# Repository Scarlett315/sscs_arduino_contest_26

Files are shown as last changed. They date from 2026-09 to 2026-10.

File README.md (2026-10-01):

Documentation & process can be found [here](https://medium.com/@scarlettchen315/lock-in-box-2-functional-version-dc13c8e9974b).

Includes 3-D printed box, custom PCB, and Arduino code. 
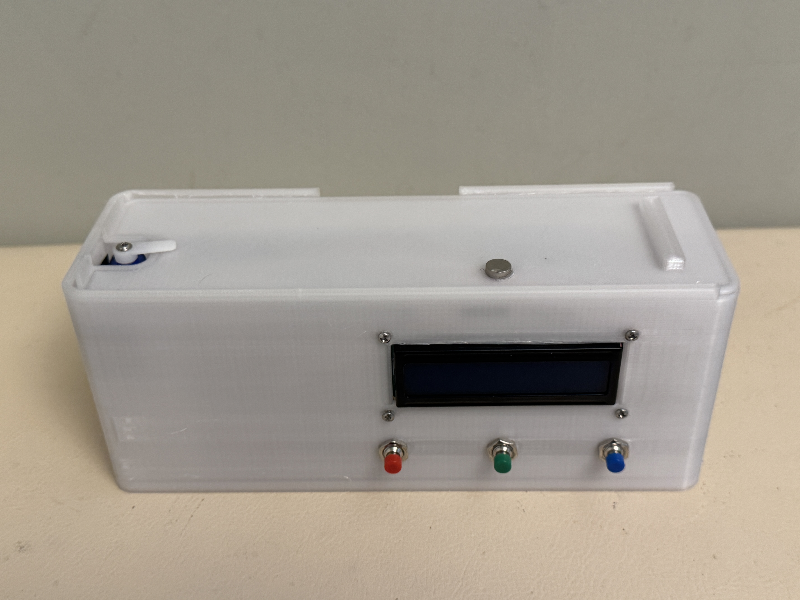
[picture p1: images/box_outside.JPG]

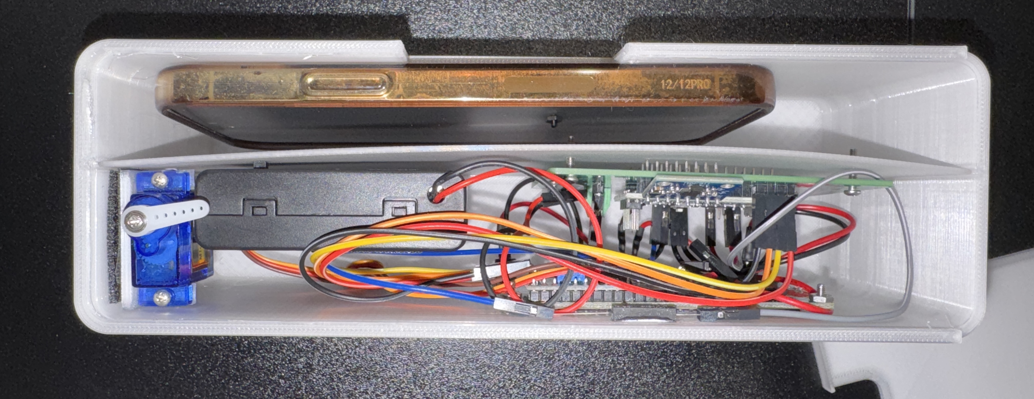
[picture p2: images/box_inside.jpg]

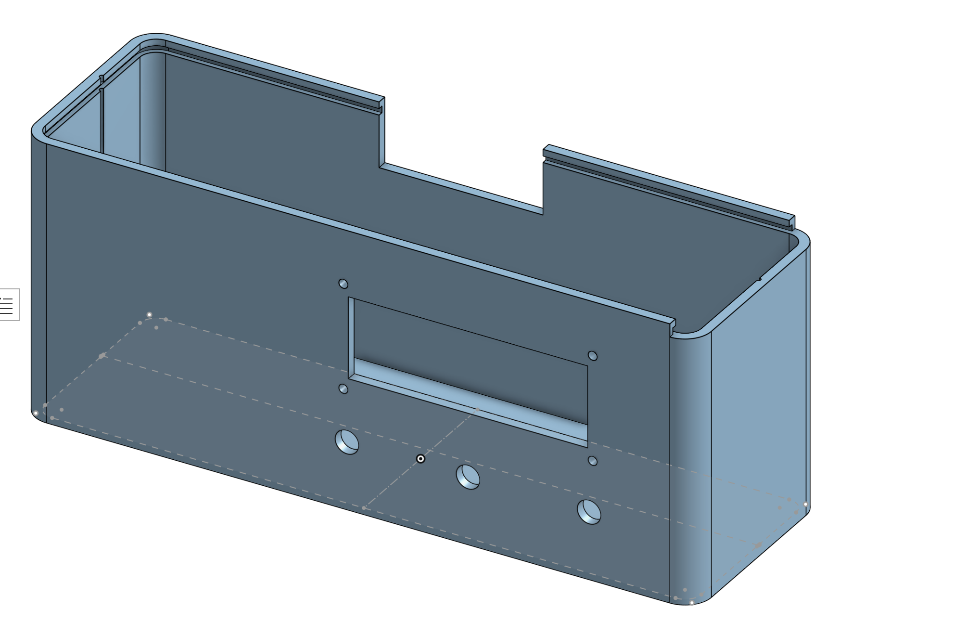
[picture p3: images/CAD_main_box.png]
main box

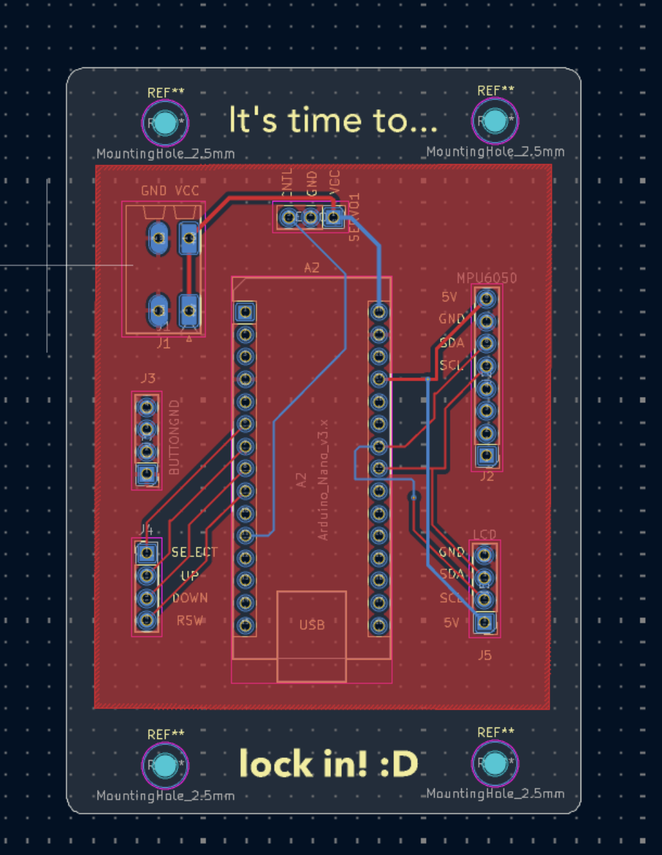
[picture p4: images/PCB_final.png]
PCB


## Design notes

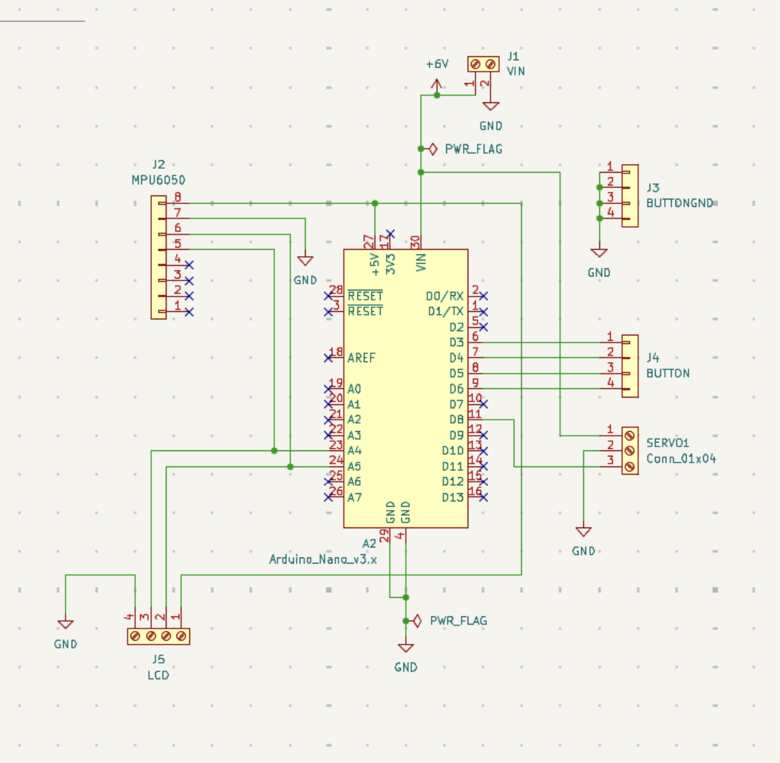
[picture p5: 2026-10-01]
images/schematic_final.png

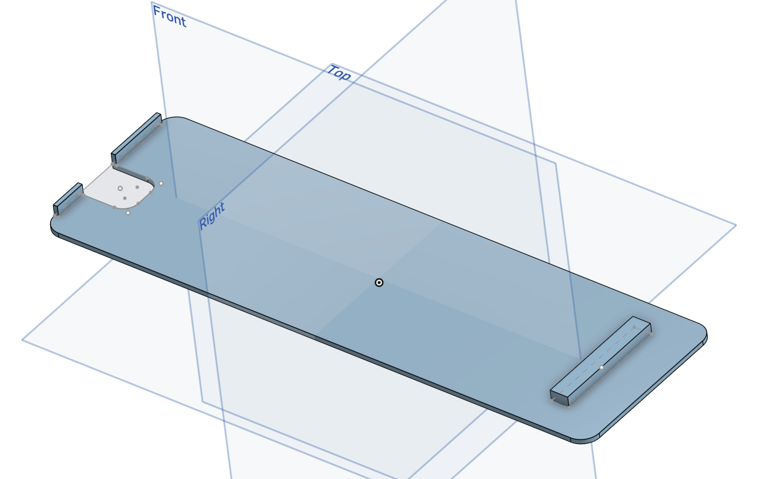
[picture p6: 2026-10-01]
images/CAD_lid.png

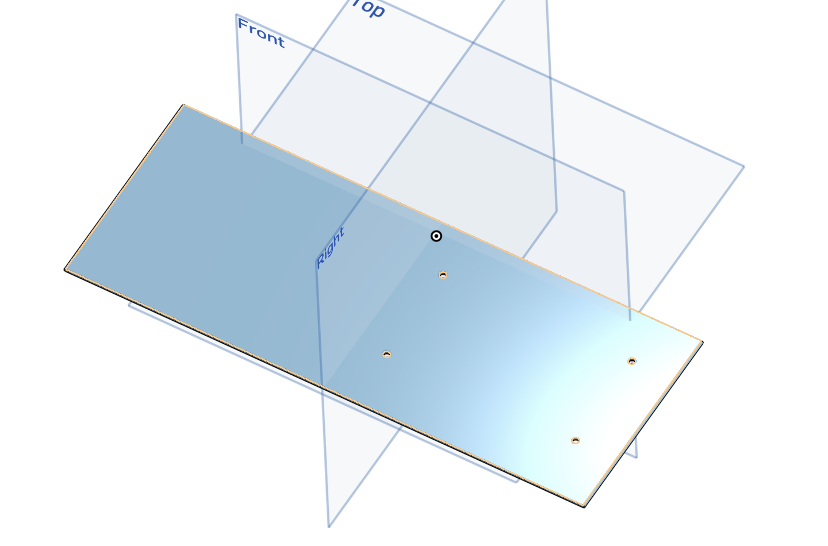
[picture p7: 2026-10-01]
images/CAD_divider.png

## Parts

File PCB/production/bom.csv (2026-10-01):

Designator | Footprint | Quantity | Value | LCSC Part #
A2 | Arduino_Nano | 1 | Arduino_Nano_v3.x
J1 | PhoenixContact_SPT_1.5_2-H-3.5_1x02_P3.5mm_Horizontal | 1 | VIN
J2 | PinHeader_1x08_P2.54mm_Vertical | 1 | MPU6050
J3 | PinHeader_1x04_P2.54mm_Vertical | 1 | BUTTONGND
J4 | PinHeader_1x04_P2.54mm_Vertical | 1 | BUTTON
J5 | PinHeader_1x04_P2.54mm_Vertical | 1 | LCD
SERVO1 | PinHeader_1x03_P2.54mm_Vertical | 1 | Conn_01x04

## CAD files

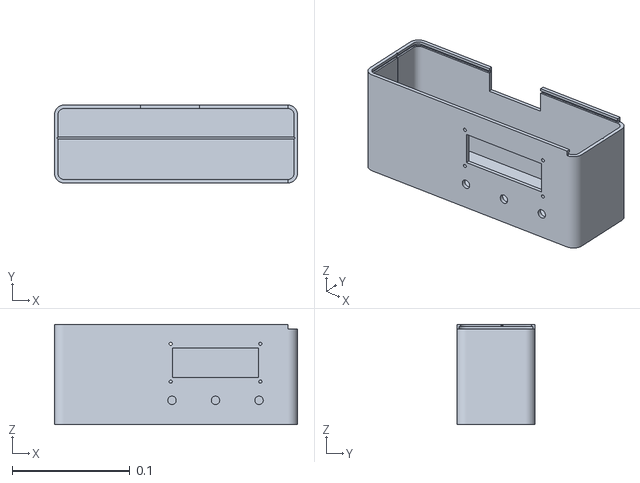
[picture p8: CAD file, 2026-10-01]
CAD Models/main_box_1.stl
0.206 x 0.066 x 0.085

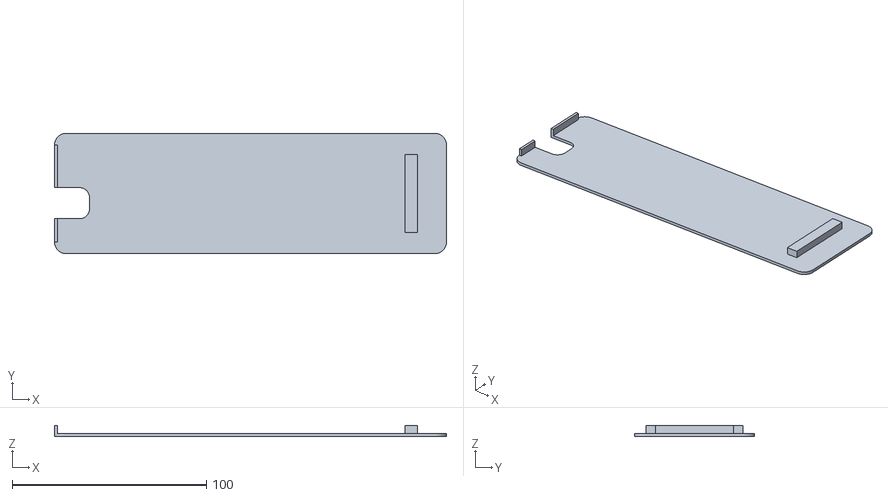
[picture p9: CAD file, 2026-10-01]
CAD Models/lid_2.stl
202.0 x 62.0 x 5.60

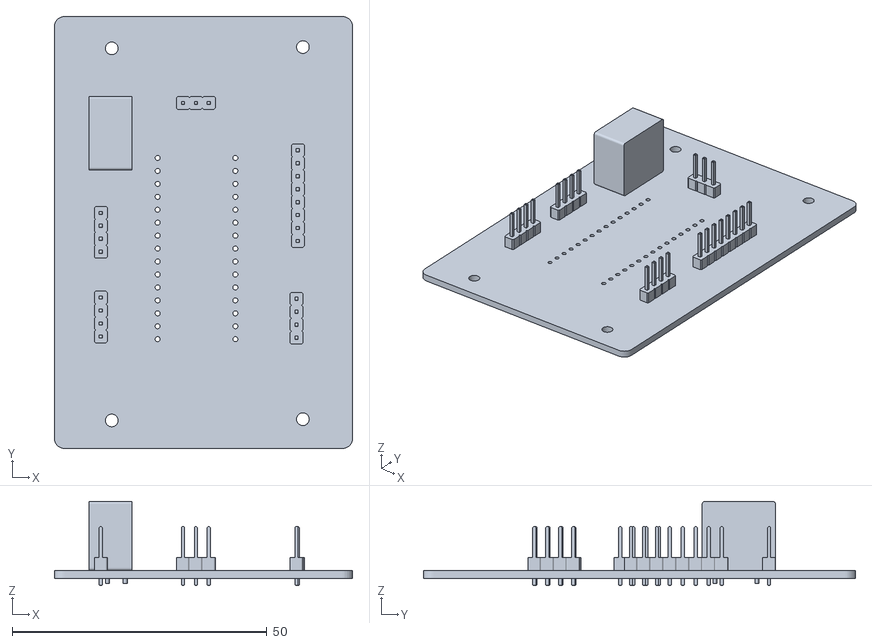
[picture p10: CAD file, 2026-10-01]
PCB/.stl
58.5 x 84.8 x 16.5

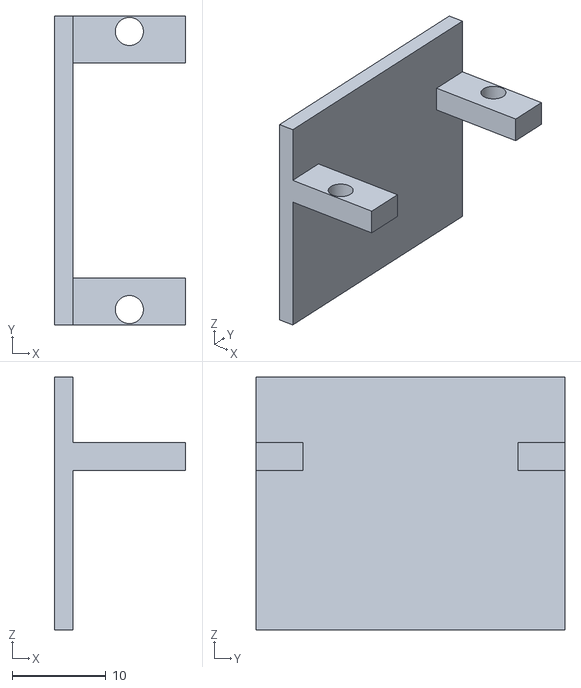
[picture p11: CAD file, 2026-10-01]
CAD Models/servo_holder.stl
14.0 x 33.0 x 27.0

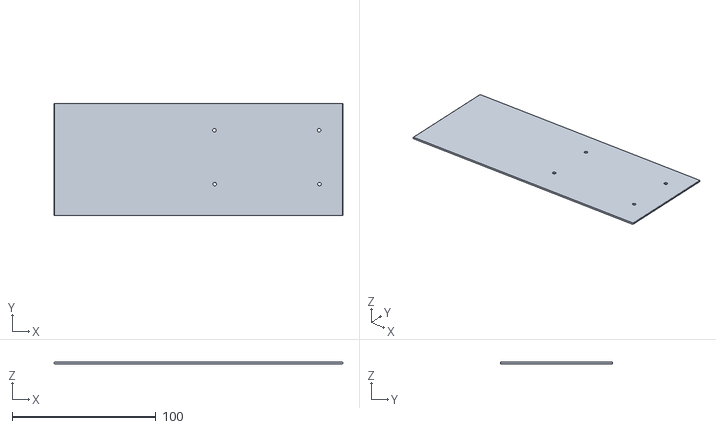
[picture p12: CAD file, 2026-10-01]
CAD Models/divider.stl
201.2 x 78.0 x 1.24

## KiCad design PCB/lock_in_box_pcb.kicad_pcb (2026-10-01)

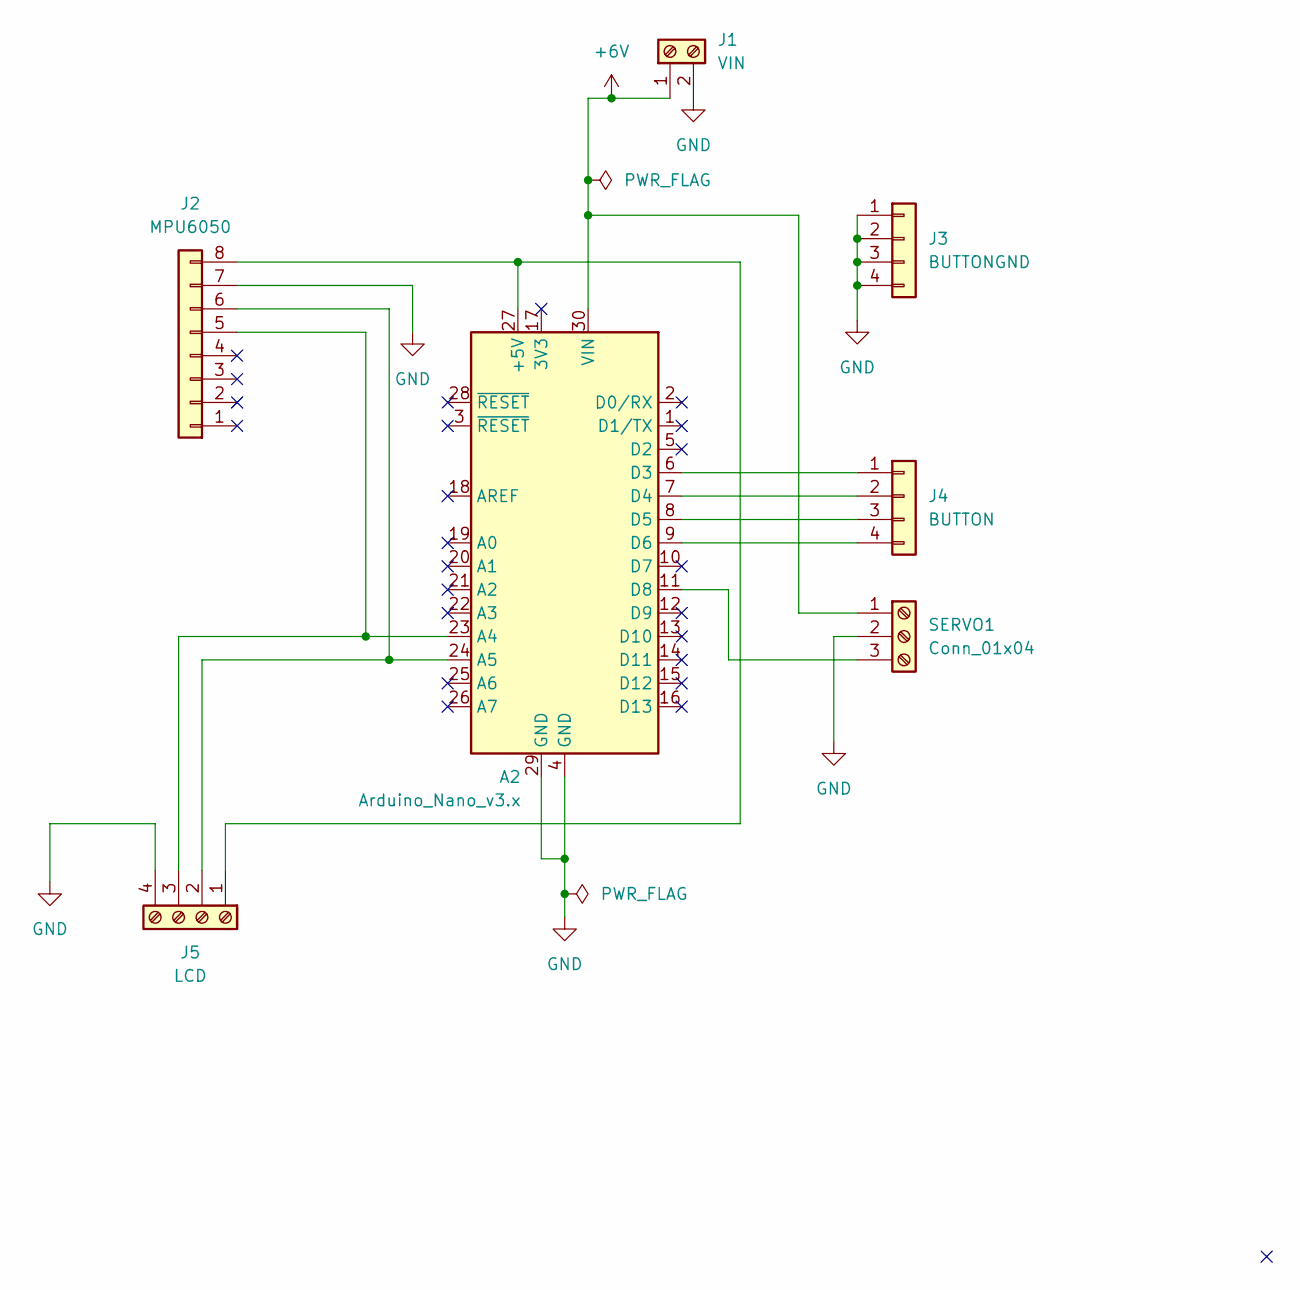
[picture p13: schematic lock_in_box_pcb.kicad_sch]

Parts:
A2: Arduino_Nano_v3.x; Arduino_Nano
J1: VIN; PhoenixContact_SPT_1.5_2-H-3.5_1x02_P3.5mm_Horizontal
J2: MPU6050; PinHeader_1x08_P2.54mm_Vertical
J3: BUTTONGND; PinHeader_1x04_P2.54mm_Vertical
J4: BUTTON; PinHeader_1x04_P2.54mm_Vertical
J5: LCD; PinHeader_1x04_P2.54mm_Vertical
SERVO1: Conn_01x04; PinHeader_1x03_P2.54mm_Vertical

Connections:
+6V: A2.30 (VIN), J1.1, SERVO1.1
GND: A2.4 (GND), A2.29 (GND), J1.2, J2.7, J3.1, J3.2, J3.3, J3.4, J5.4, SERVO1.2
unnamed: A2.27 (+5V), J2.8, J5.1
unnamed: A2.23 (A4), J2.5, J5.3
unnamed: A2.24 (A5), J2.6, J5.2
unnamed: A2.6 (D3), J4.1
unnamed: A2.7 (D4), J4.2
unnamed: A2.8 (D5), J4.3
unnamed: A2.9 (D6), J4.4
unnamed: A2.11 (D8), SERVO1.3

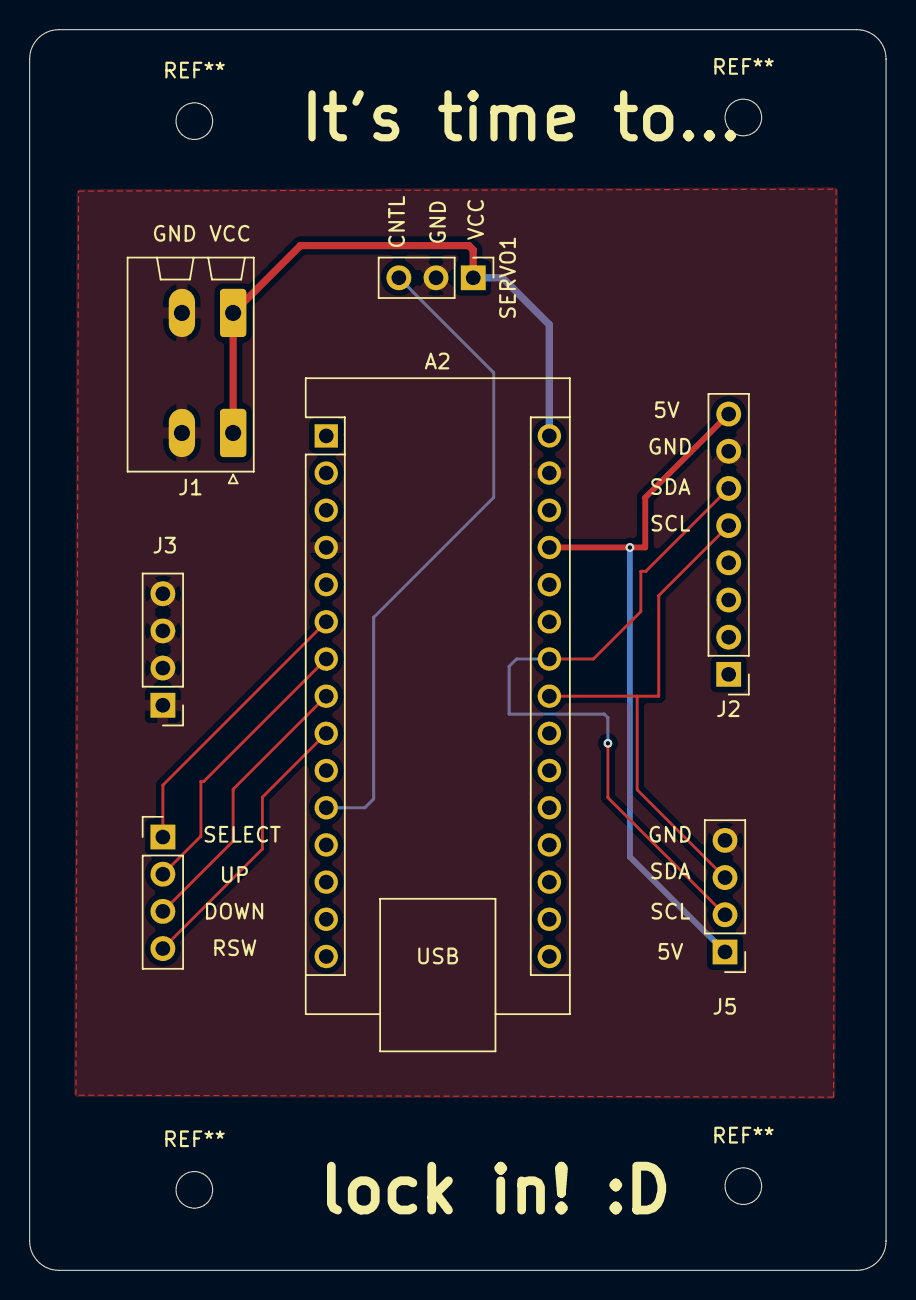
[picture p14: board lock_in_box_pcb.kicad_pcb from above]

Board: 2 copper layers, 58.5 x 84.8 mm, 7 parts (0 on the bottom side), 10 nets.

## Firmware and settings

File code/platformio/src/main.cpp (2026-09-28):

#include <Arduino.h>
#include <Servo.h>
#include <Wire.h>  // I2C
#include <LiquidCrystal_I2C.h> // LCD
#include <Adafruit_MPU6050.h>
#include <Adafruit_Sensor.h>

// ----------- PINS / OBJECTS -----------------------------
Servo servo;  // create servo object to control a servo
LiquidCrystal_I2C lcd(0x27,20,4);  // set the LCD address to 0x27 for a 16 chars and 2 line display
Adafruit_MPU6050 mpu; // MPU6050

#define SERVO_CONTROL_PIN 8
#define SELECT_BUTTON 3
#define UP_BUTTON 4
#define DOWN_BUTTON 5 
#define REED_SWITCH 6

// button intialization
bool select_button_state = 0, up_button_state = 0, down_button_state = 0, reed_sw_state = 0;
bool select_button_delay = 0, up_button_delay = 0, down_button_delay = 0;
unsigned long last_debounce_time;

unsigned int DEBOUNCE_TIME = 100;

// ----------------- VARIABLES ---------------------------
//servo
int pos = 0;  
int LOCKED_POS = 150;
int UNLOCKED_POS = 30;

// selection
unsigned int LOCK_TIME_INTERVAL = 900; // in seconds (15 mins)

// timing
unsigned long now = 0;
unsigned long last_print = 0;

// timer
unsigned volatile int lock_time_s = 900; // seconds
unsigned long lock_time_start;
unsigned long time_left;
unsigned long elapsed;

unsigned int time_disp_s, time_disp_mins, time_disp_hrs;

//display
char lcd_buffer[16]; 
bool update_lcd = false;

// --------- VIBRATION DETECT stuff -----------
float a_z; // we are only using z-accel
unsigned long last_IMU_update = 0;
bool vib_detect_enable = false; // servo causes vibration

// adjustment/filter
float z_DRIFT_CORRECTION = 0;
float z_baseline = 0;
const float HP_COEFF = 0.10;  // high-pass filter

//RMS
float running_sum = 0;
float mean = 0;
float RMS = 0;

const int RMS_SAMPLES = 50;
int rms_counter = 0; 

// thresholds & sliding window :O
const float THRESHOLD_HIGH = 0.50;
const float THRESHOLD_LOW = 0.40;

const int WINDOW = 30;
const int REQUIRED = 24;

bool history[WINDOW] = {0}; // sliding list of bools
int history_index = 0;
int vibration_ct = 0;

bool vibration_detected = false; // final result
unsigned long stabilization_start = 0;


// ---------- FUNCTION DECLARATIONS -------
bool servo_lock(int target_pos);
bool rising_edge_detect(bool button_state, bool carry_state);
void calc_display_times(unsigned long input_time_s);
void reset_all_timer_vars();
void update_accels();
void calibrate_IMU();
bool vibration_detect();
void setup_IMU();
void reset_all_vibration_vars();

// ---------------- FSM SETUP ----------------
enum FSM_States {
  IDLE,
  LOCKED,
  TAMPER, // timer not completed & lid open
  PAUSE   // timer not completed & lid closed, wait for resume
};

FSM_States state = IDLE;

// ----------------- SETUP -------------------
void setup() {
  Serial.begin(9600);

  // Servo
  servo.attach(SERVO_CONTROL_PIN);  // attaches the servo on pin 9 to the servo object

  // Button + reed switch inputs
  pinMode(SELECT_BUTTON, INPUT_PULLUP);
  pinMode(UP_BUTTON, INPUT_PULLUP);
  pinMode(DOWN_BUTTON, INPUT_PULLUP); 
  pinMode(REED_SWITCH, INPUT_PULLUP);
  
  // LCD
  lcd.init();      
  lcd.backlight();
  lcd.cursor();   
  
  lcd.setCursor(0, 0);
  lcd.print("Time to lock in!"); 

  //IMU
  setup_IMU();
}

// --------------- LOOP --------------------
bool sec_tick = false;
unsigned long last_sec_update = 0;

void loop() {

  // ------------------- UPDATES ------------------
  now = millis();
  update_lcd = false;
  sec_tick = false;

  vib_detect_enable = (state == LOCKED) && (now - stabilization_start > 300);

  if (now - last_sec_update >= 1000){
    sec_tick = true;
    last_sec_update = now;
  }

  // debug prints
  if (millis() - last_print >= 200){
    Serial.print("State: ");
    Serial.print(state);
    Serial.print("| Servo Position: ");
    Serial.print(pos);
    //Serial.print("| Start time: ");
    //Serial.print(lock_time_start);
    Serial.print("| Lock Time: " );
    Serial.print(lock_time_s);
    //Serial.print("| seconds_left: " );
    //Serial.print(time_left);
    Serial.print("| " );
    Serial.print(time_disp_mins);
    Serial.print(" : " );
    Serial.print(time_disp_s);
    Serial.print("| Reed Switch" );
    Serial.print(reed_sw_state);
    Serial.print("| Vibration: " );
    Serial.print(vibration_detected);
    Serial.print("| V_en: " );
    Serial.print(vib_detect_enable);
    Serial.print("| RMS: " );
    Serial.print(RMS);
    Serial.print("| vibration ct " );
    Serial.print(vibration_ct);
    //Serial.print("history " );
    //Serial.print(history);
    Serial.println();

    last_print = now;
  }

  // button states (going through debounce + edge detect)
  if ( (now - last_debounce_time) > DEBOUNCE_TIME) {
    // INPUT_PULLUP --> reverse state
    bool select_raw = !digitalRead(SELECT_BUTTON);
    bool down_raw = !digitalRead(DOWN_BUTTON);
    bool up_raw = !digitalRead(UP_BUTTON);

    // detect a new button press
    select_button_state = rising_edge_detect(select_raw, select_button_delay);
    down_button_state = rising_edge_detect(down_raw, down_button_delay);
    up_button_state = rising_edge_detect(up_raw, up_button_delay);

    // save the raw states for the next iteration
    select_button_delay = select_raw;
    down_button_delay = down_raw;
    up_button_delay = up_raw;

    reed_sw_state = !digitalRead(REED_SWITCH);

    last_debounce_time = now;
  }

  if ( (now - last_IMU_update) > 10 && vib_detect_enable){
    update_accels();
    vibration_detected = (vibration_detect());
  } else {
    reset_all_vibration_vars();
  }

  // ----------------------- FSM -------------------------

  switch (state){ 
    case IDLE: 
      if (servo_lock(UNLOCKED_POS)){ // wait for it to finish unlocking

        // whenever SELECT_BUTTON is pressed, lock
        if (select_button_state){
          time_left = lock_time_s;
          select_button_state = false;

          stabilization_start = now;
          state = LOCKED;
        }

        // time selection
        if (down_button_state) {
          lock_time_s = (lock_time_s < LOCK_TIME_INTERVAL)? 0 : lock_time_s - LOCK_TIME_INTERVAL; // no negative time lol
          down_button_state = false;
          
          calc_display_times(lock_time_s);
          snprintf(lcd_buffer, sizeof(lcd_buffer), "    %02d:%02d:%02d", time_disp_hrs, time_disp_mins, time_disp_s);
          update_lcd = true;
        }

        if (up_button_state){
          lock_time_s = lock_time_s + LOCK_TIME_INTERVAL;
          up_button_state = false;

          calc_display_times(lock_time_s);
          snprintf(lcd_buffer, sizeof(lcd_buffer), "    %02d:%02d:%02d", time_disp_hrs, time_disp_mins, time_disp_s);
          update_lcd = true;
        }

      }
      break;
      
    case LOCKED:
      if (servo_lock(LOCKED_POS)){ // wait for it to finish locking
        unsigned long old_time_left = time_left;
        time_left = (sec_tick)? time_left - 1:time_left;

        // re-calculating timer things
        if (time_left <= 0){ // timer is finished
            reset_all_timer_vars();
            snprintf(lcd_buffer, sizeof(lcd_buffer), "TIME TO LOCK IN");
            state = IDLE; // yippee :>
        } else {
            calc_display_times(time_left);
        }

        // LCD updates only when time changes  
        if (old_time_left != time_left){
          snprintf(lcd_buffer, sizeof(lcd_buffer), "    %02d:%02d:%02d", time_disp_hrs, time_disp_mins, time_disp_s);
          update_lcd = true;
        }

        // tamper detection
        if (!reed_sw_state){
          snprintf(lcd_buffer, sizeof(lcd_buffer), "    CLOSE LID");
          update_lcd = true;
          state = TAMPER;
        }

        // "phone call" vibration detection
        if (vibration_detected){
          snprintf(lcd_buffer, sizeof(lcd_buffer), "BLUE TO RESUME");
          update_lcd = true;
          state = PAUSE;
        }
      }
      
      break;

    case TAMPER:
        if (servo_lock(UNLOCKED_POS)){ // servo should be unlocked so that you can put the lid back down
            if (reed_sw_state){ // box is closed again, allow to resume

              delay(200); // a bit glitchy
              snprintf(lcd_buffer, sizeof(lcd_buffer), "BLUE TO RESUME");
              update_lcd = true;
              state = PAUSE;
            } else {
              state = TAMPER;
            }
        }
      break;

    case PAUSE:
        if (servo_lock(UNLOCKED_POS)){

          if (reed_sw_state){
            if (select_button_state){ // go back to LOCKED once middle button is pressed
              delay(200); 
              stabilization_start = now;
              state = LOCKED;
            } else {
              state = PAUSE;
            }
          } else { // if lid is opened again, go back to TAMPER :P
            snprintf(lcd_buffer, sizeof(lcd_buffer), "    CLOSE LID");
            update_lcd = true;
            state = TAMPER; 
          }
        } 
      break;

    default: state = IDLE;
  }   
    


  // LCD update (whenever something changes)
  if (update_lcd){
    lcd.setCursor(0,0);
    lcd.print("                    ");  // clear line 
    lcd.setCursor(0,0);
    lcd.print(lcd_buffer);
  }
}

// ------------ FUNCTIONS -----------------


// edge detect (buttons should only register once)
bool rising_edge_detect(bool button_state, bool carry_state){ 

    //if the state switches from low to high, there is a rising edge
    if (carry_state == 0 && button_state == 1){
        return true;
    }
    return false;
}

// controls servo angle (lock)
bool servo_lock(int target_pos){ 
  if (pos == target_pos){
    return true;
  } 

  // write in increments
  pos = (target_pos > pos)? (pos + 1):(pos - 1);
  servo.write(pos);
  return false;
}

void calc_display_times(unsigned long input_time_s){
  time_disp_hrs = (input_time_s / 60) / 60;
  time_disp_mins = (input_time_s / 60) % 60;
  time_disp_s = input_time_s % 60;
}

void reset_all_timer_vars(){
  lock_time_s = 0;
  lock_time_start = 0;
  time_left = 0;
  time_disp_s = 0;
  time_disp_mins = 0;
  time_disp_hrs = 0;
  elapsed = 0;
}

// for vibration detection

//functions

void calibrate_IMU(){
  const int samples = 200;

  float z = 0;

  for (int i = 0; i < samples; i++) {
      sensors_event_t a, g, temp;
      mpu.getEvent(&a, &g, &temp);

      z = a.acceleration.y;
      
      z_DRIFT_CORRECTION += z;

      delay(5);
  }
  z_DRIFT_CORRECTION /= samples;
  }

void setup_IMU() {
  // Try to initialize!
  if (!mpu.begin()) {
    Serial.println("Failed to find MPU6050 chip");
    while (1) {
      delay(10);
    }
  }
  Serial.println("MPU6050 Found!");

  mpu.setAccelerometerRange(MPU6050_RANGE_2_G);
  mpu.setGyroRange(MPU6050_RANGE_500_DEG);
  mpu.setFilterBandwidth(MPU6050_BAND_260_HZ);

  Serial.println("Calibrating...");
  calibrate_IMU();
  Serial.println("Z DRIFT CORRECTION: ");
  Serial.print(z_DRIFT_CORRECTION);

  Serial.println();
  
  delay(100);
}

// update acceleration values
void update_accels(){
  sensors_event_t a, g, temp;
  mpu.getEvent(&a, &g, &temp);

  a_z = a.acceleration.y - z_DRIFT_CORRECTION;

  // high-pass filter (gets rid of *gravity* :>)
  z_baseline += HP_COEFF * (a_z - z_baseline);
  float z_hp = a_z - z_baseline;

  rms_counter += 1;
  running_sum += sq(z_hp);

  if (rms_counter >= RMS_SAMPLES){
    mean = running_sum / RMS_SAMPLES;
    RMS = sqrt(mean);
    rms_counter = 0;
    running_sum = 0;
  }
}

// if 8/10 of the last RMS readings are above the threshold (400/500ms), vibration is detected!!!
bool vibration_detect(){
  bool vib_in_range = (RMS < THRESHOLD_HIGH && RMS > THRESHOLD_LOW);
  
  // remove oldest sample
  if (history[history_index]){
      vibration_ct--;
  }

  // store new sample
  history[history_index] = vib_in_range;

  if (vib_in_range)
      vibration_ct++;

  // increment and wrap-around if needed
  history_index = (history_index + 1) % WINDOW;

  // the result!
  return (vibration_ct >= REQUIRED);
}

void reset_all_vibration_vars(){
  running_sum = 0;
  rms_counter = 0;
  RMS = 0;

  memset(history, 0, sizeof(history));
  vibration_ct = 0;
  history_index = 0;

  vibration_detected = false;
}

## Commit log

2026-07-24 buttons for increase/decrease time + buttons are debounced & edge-detected!
2026-07-25 lcd formatting + reed switch is working!
2026-09-22 backup before adjustment to pcb
2026-10-01 added all files + images!
    [.stl, bom.csv, designators.csv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]
